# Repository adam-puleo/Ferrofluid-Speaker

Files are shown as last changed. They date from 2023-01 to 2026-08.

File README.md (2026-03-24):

# Ferrofluid-Speaker
A ferrofluid Bluetooth speaker.

Use --recurse-submodules to clone this repo: ```git clone --recurse-submodules https://github.com/adam-puleo/Ferrofluid-Speaker.git```

## Version 2
https://github.com/user-attachments/assets/a1edecc6-fbbd-465e-8119-4edb1a70faee

## Version 2 Front
v2_front

## Version 2 Back
v2_back

## Prototype


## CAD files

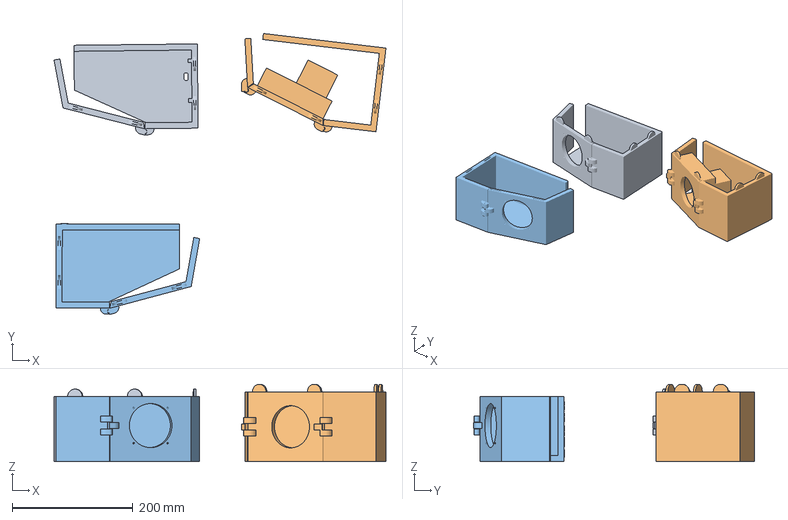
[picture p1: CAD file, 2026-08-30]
Case/Tilted Case Frame.3mf
550.5 x 466.0 x 128.5 mm
Tilted Case Frame Left
Tilted Case Frame Middle
Tilted Case Frame Right

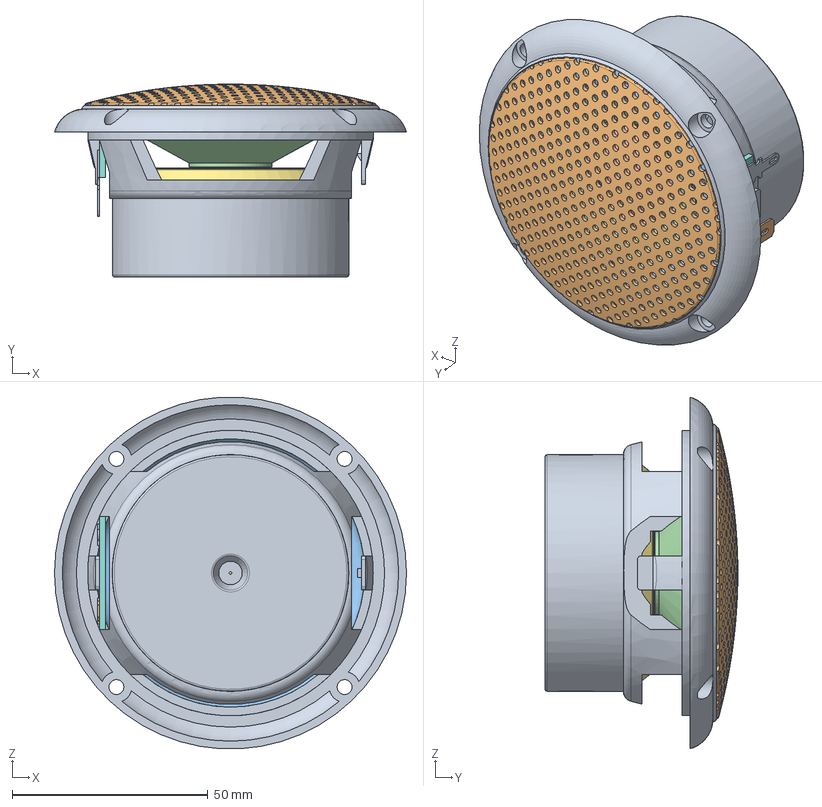
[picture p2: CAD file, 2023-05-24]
Case/VISATON FR 8 WP 130814-igs-stp/FR 8 WP 130814.stp
90.0 x 49.3 x 89.8 mm
FR 8 WP - Korb 130814
FR 8 WP - Gitter 130814
FR 8 WP - T-Yoke 130814
FR 8 WP - Magnet 130814
FR 8 WP - Polplatte 130814
FR 8 WP - Schraube für Magnetbefestigung 130814
FR 8 WP - Terminalplatte 130814
_Terminal 2.8-0.5
_Terminal 5.1-0.5
FR 8 WP - Sicke 130814
FR 8 WP - Membran 130814
FR 8 WP - Staubschutzkalotte 130814
FR 8 WP - Spule 130814
FR 8 WP - Zentrierspinne 130814

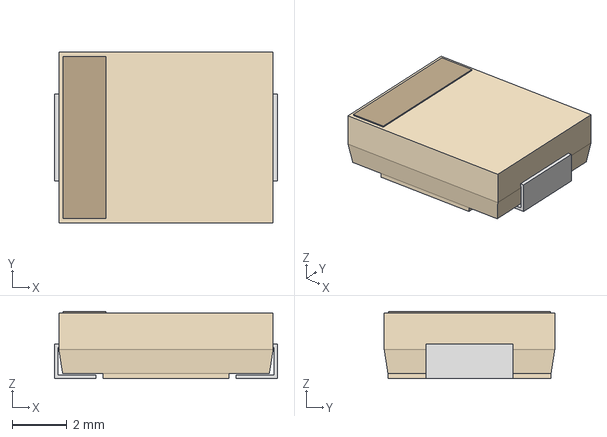
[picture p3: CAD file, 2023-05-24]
Circuits/Main Circuit/B520C-13-F/SMC_DIO.step
8.13 x 6.22 x 2.45 mm

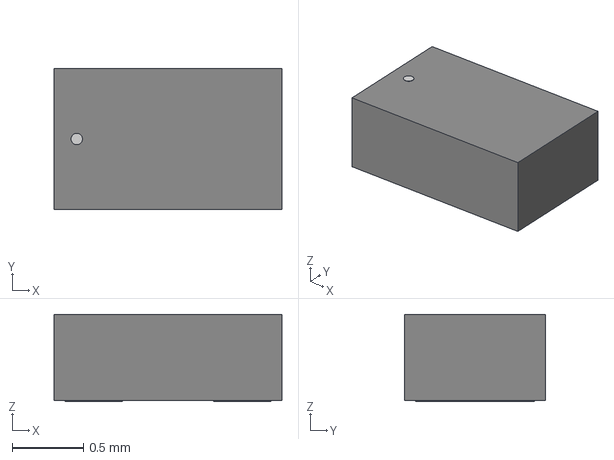
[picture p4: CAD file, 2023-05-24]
Circuits/Main Circuit/ESDA25P35-1U1M/QFN1610_STM.step
1.60 x 0.99 x 0.612 mm

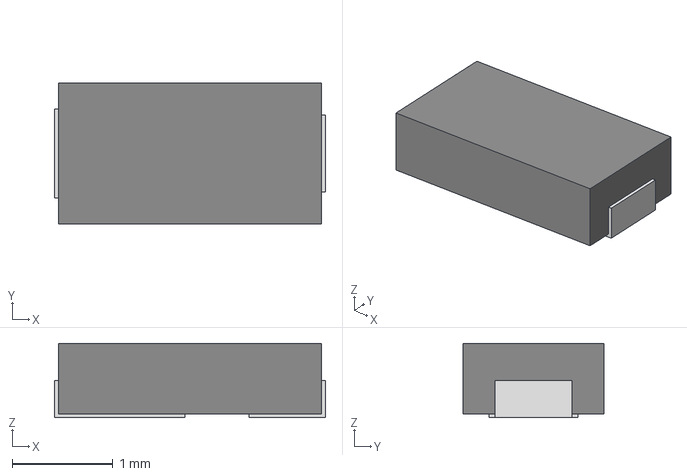
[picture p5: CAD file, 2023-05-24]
Circuits/Main Circuit/MSS1P3L-M3:89A/DIODE_MSP3V3.step
2.69 x 1.40 x 0.737 mm

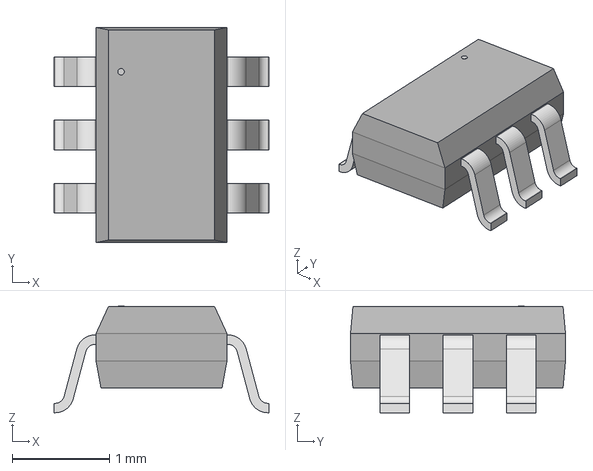
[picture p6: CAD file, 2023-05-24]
Circuits/Main Circuit/NVJS4405NT1G/SOT-363-6_2P2X1P35_ONS.step
2.21 x 2.21 x 1.09 mm

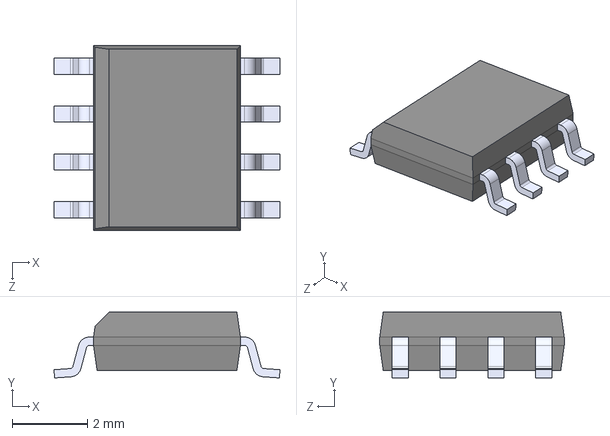
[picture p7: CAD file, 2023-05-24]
Circuits/Main Circuit/SI4485DY-T1-GE3.STEP
6.00 x 1.75 x 4.90 mm

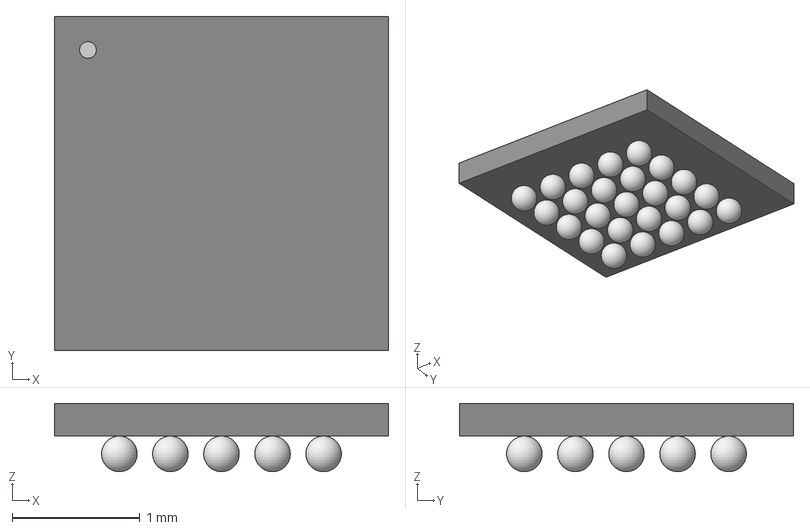
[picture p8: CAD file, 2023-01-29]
Circuits/Main Circuit/ul_STUSB4500BJR/Fusion360/BGA_00BJR_STM.step
2.62 x 2.62 x 0.536 mm

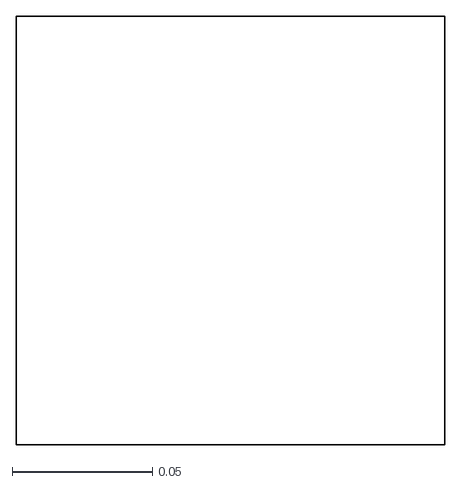
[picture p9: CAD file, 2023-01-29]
Circuits/Main Circuit/ul_STUSB4500BJR/Library_View.dxf
0.153 x 0.153

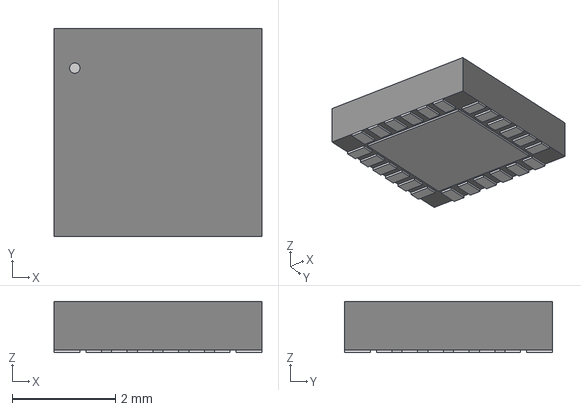
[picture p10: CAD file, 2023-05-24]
Circuits/Main Circuit/ul_STUSB4500QTR/Fusion360/QFN24EP_4X4_STM.step
4.04 x 4.04 x 0.993 mm

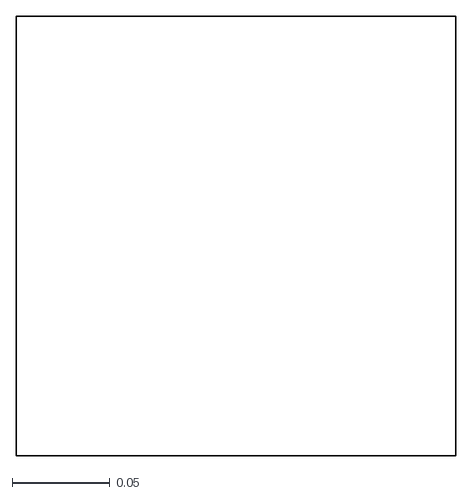
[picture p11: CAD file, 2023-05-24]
Circuits/Main Circuit/ul_STUSB4500QTR/Library_View.dxf
0.225 x 0.225

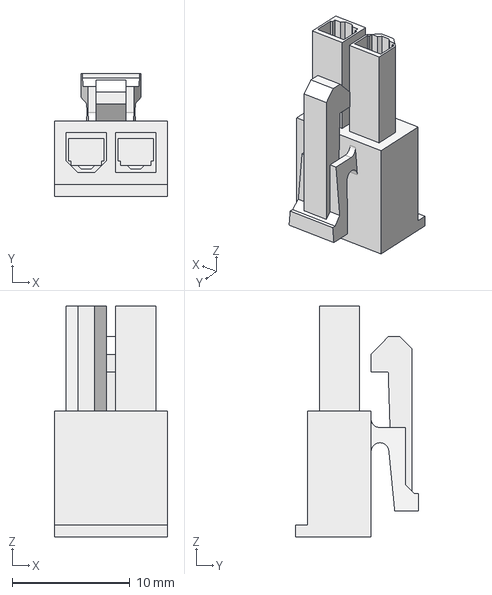
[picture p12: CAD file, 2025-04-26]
Case/Download_STP_649002013322_rev1.stp
9.60 x 10.4 x 19.6 mm

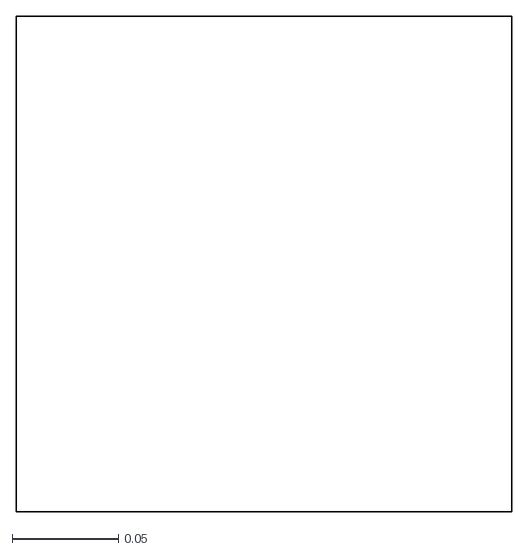
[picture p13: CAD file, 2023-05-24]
Circuits/Main Circuit/ul_STUSB4500QTR/QFN24EP_4X4_STM.dxf
0.233 x 0.233

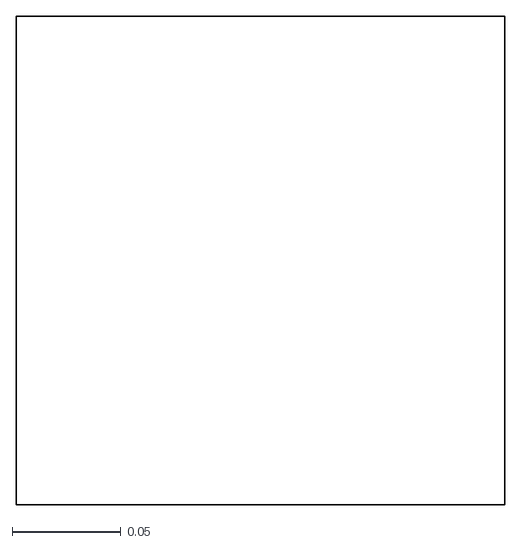
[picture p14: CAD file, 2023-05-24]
Circuits/Main Circuit/ul_STUSB4500QTR/QFN24EP_4X4_STM-L.dxf
0.225 x 0.225

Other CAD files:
Circuits/Main Circuit/ul_STUSB4500QTR/QFN24EP_4X4_STM-M.dxf
Electromagnets/EM175GenericModel v2.f3d
Ferrofluid Bottles/Ferrofluid Bottle v4.f3d

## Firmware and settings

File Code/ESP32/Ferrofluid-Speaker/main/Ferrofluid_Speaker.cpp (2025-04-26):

/*
    Inspiration for this came from Seung Hoon Jung's ferrofluid speaker.
    https://makezine.com/article/craft/fine-art/we-cant-stop-watching-this-diy-ferrofluid-bluetooth-speaker/

    Tested with ESP-ADF v2.7 (db46237027988356673c150348c3294862105d51), ESP-IDF v5.4, ESP32-A2DP v1.8.7, arduino-audio-tools (13ae8ea75c7113f048f28e11d91357942e93716f)

    menuconfig
    Partition Table
        Partition Table
            Single factory app (large), no OTA
    Compiler options
        Optimization Level -> Optimize for performance (-O2)
    Component config
        Bluetooth
            Controller Options
                Bluetooth controller mode -> BR/EDR Only
            Bluedroid Options
                Classic Bluetooth -> A2DP & SPP
        Log
            Log Level
                Default log verbosity -> No output

    Test Music:
        Artist: Tom Misch
        Album: Geography
        Song: Movie

        Artist: Metallica
        Album: 72 Seasons
        Song: Lux Æterna

        Artist: Ozzy Osbourne
        Album: Memoirs of a Madman
        Song: Crazy Train

        Artist: Queens of the Stone Age
        Album: Songs for the Deaf
        Song: No One Knows

        Artist: Iron Maiden
        Album: Senjutsu
        Song: Senjutsu
*/

#include <time.h>
#include <stdio.h>
#include <stdlib.h>
#include <string.h>
#include <assert.h>
#include "freertos/FreeRTOS.h"
#include "freertos/task.h"
#include "esp_system.h"
#include "esp_dsp.h"
#include "driver/i2c_master.h"
#include "driver/gpio.h"
#include "esp_timer.h"

#include "AudioTools.h"
#include "BluetoothA2DPSink.h"
#include "TAS5805M.hpp"
#include "STUSB4500.hpp"

// Vars for logging
const char *TAG = "Ferrofluid";
const int64_t OUTPUT_INTERVAL = 2000000; // Two seconds
int64_t last_output = 0;

// Setup aliases for GPIO pins that drive the electromagnet.
const gpio_num_t MAGNET = GPIO_NUM_5;

// Fast fourier transform variables.
const size_t NUM_FFT_SAMPLES = 4096 / 2 / 2; // See read_data_stream
static_assert(NUM_FFT_SAMPLES == 1024, "FFT lib requires 1024 samples.");
// Window coefficients
__attribute__((aligned(16))) float fft_window[NUM_FFT_SAMPLES];
// working complex array
__attribute__((aligned(16))) float y_cf[NUM_FFT_SAMPLES * 2];
// Pointers to result arrays
float *fft_output_left = &y_cf[0];
float *fft_output_right = &y_cf[NUM_FFT_SAMPLES];

// Setup config constants for ESP's I2C communications.
const uint32_t I2C_FREQUENCY = 400000;
const i2c_port_t I2C_PORT = I2C_NUM_0;
const uint8_t AMP_ADDR = 0x2C;      // Amp's I2C address (8-bit write address: 0x58)
const uint8_t USB_CTRL_ADDR = 0x2B; // USB controller's I2C address (8-bit write address: 0x56)
const int I2C_XFER_TIMEOUT = -1;
const gpio_num_t I2C_GPIO_SCL = GPIO_NUM_19;
const gpio_num_t I2C_GPIO_SDA = GPIO_NUM_18;
i2c_master_bus_config_t i2c_mst_config = {
    .i2c_port = I2C_PORT,
    .sda_io_num = I2C_GPIO_SDA,
    .scl_io_num = I2C_GPIO_SCL,
    .clk_source = I2C_CLK_SRC_DEFAULT,
    .glitch_ignore_cnt = 7,
    .intr_priority = 0,
    .trans_queue_depth = 0,
    .flags{.enable_internal_pullup = true, // ESP32's pull-ups are only good for 100kHz; set to true to remove warning.
           .allow_pd = false,
        },
};
i2c_master_bus_handle_t bus_handle;

// Setup aliases for GPIO pins that communicate with the amp.
const gpio_num_t PDN = GPIO_NUM_23;
const gpio_num_t FAULT = GPIO_NUM_21;
const gpio_num_t I2S_LRCLK = GPIO_NUM_25;
const gpio_num_t I2S_SCLK = GPIO_NUM_26;
const gpio_num_t I2S_DIN = GPIO_NUM_22;

// I2C interface variables for TAS5805M.
i2c_wrapper *i2c_tas5805m;
TAS5805M *amp;

// Constants for USB / power requirements.
const unsigned int M_VOLTS = 12000; // Millivolts
const unsigned int M_AMPS = 1000;   // Milliamps

// I2C interface variables to STUSB4500.
i2c_wrapper *i2c_usb_ctrler;
STUSB4500 *usb_ctrler;

// Setup the Bluetooth A2DP sink and I2S.
I2SStream i2s;
BluetoothA2DPSink a2dp_sink(i2s);

#define CHECK_ERROR(error_code, ...)  \
    if (error_code != ESP_OK)         \
    {                                 \
        ESP_LOGE(TAG, ##__VA_ARGS__); \
        return error_code;            \
    }

void read_data_stream(const uint8_t *data, uint32_t length)
{
    // *data contains left and right channel data. First two bytes is left (int16_t).
    // Next two bytes is the right channel data. length contains the total number of
    // bytes.
    ESP_LOGD(TAG, "Length: %d", length);
    size_t sample_count = length / 2 / 2;
    if (sample_count != NUM_FFT_SAMPLES)
    {
        ESP_LOGE(TAG, "Sample Count: %d", sample_count);
        assert(sample_count == NUM_FFT_SAMPLES);
    }

    // Create a new pointer cast as 16 bits.
    int16_t *samples = (int16_t *)data;

    // FFT analysis lifted from https://github.com/espressif/esp-dsp/blob/master/examples/fft/main/dsps_fft_main.c
    // Convert two input vectors to one complex vector and apply window function.
    for (int i = 0; i < NUM_FFT_SAMPLES; i++) {
        y_cf[i * 2 + 0] = float(samples[i]) * fft_window[i];
        y_cf[i * 2 + 1] = float(samples[i + 1]) * fft_window[i];
    }

    // Execute the FFT
    dsps_fft2r_fc32(y_cf, NUM_FFT_SAMPLES);
    // Bit reverse
    dsps_bit_rev_fc32(y_cf, NUM_FFT_SAMPLES);
    // Convert one complex vector to two complex vectors
    dsps_cplx2reC_fc32(y_cf, NUM_FFT_SAMPLES);
    // FFT returns complex numbers, where the first half of y_cf is the left channel and the second
    // half of y_cf is the right channel.

    bool high_freq = false;
    const int current_volume = a2dp_sink.get_volume();
    // If the normalized value is above 63% of the max volume, turn on the magnet.
    const float fft_threshold = (float(current_volume) / INT8_MAX) * (exp2(11) - 1) * 0.63;
    for (int i = 0; i < NUM_FFT_SAMPLES / 2; i++) {
        // Compute the normalized output so it can be compared with the maximum (current volume).
        float normalized_left = 2.0 * (sqrtf(fft_output_left[i * 2 + 0] * fft_output_left[i * 2 + 0] + fft_output_left[i * 2 + 1] * fft_output_left[i * 2 + 1]) / NUM_FFT_SAMPLES);
        float normalized_right = 2.0 * (sqrtf(fft_output_right[i * 2 + 0] * fft_output_right[i * 2 + 0] + fft_output_right[i * 2 + 1] * fft_output_right[i * 2 + 1]) / NUM_FFT_SAMPLES);

        if (normalized_left > fft_threshold || normalized_right > fft_threshold)
        {
            ESP_LOGI(TAG, "Current volume: %d, Threshold: %f", current_volume, fft_threshold);
            ESP_LOGI(TAG, "%d-th freq (%dHZ) - Left: %f, Right: %f", i, (i * a2dp_sink.sample_rate()) / NUM_FFT_SAMPLES, fft_output_left[i], fft_output_right[i]);
            // ESP_LOGI(TAG, "Input Left: %d, Input Right: %d", samples[i * 2], samples[i * 2 + 1]);
            gpio_set_level(MAGNET, 1);
            high_freq = true;
            break;
        }

        if (!high_freq)
        {
            gpio_set_level(MAGNET, 0);
        }
    }
}

void i2s_state_change_pre(esp_a2d_audio_state_t state, void *obj)
{
    switch (state)
    {
    case ESP_A2D_AUDIO_STATE_STARTED:
        amp->start_pre_i2s();
        break;

    case ESP_A2D_AUDIO_STATE_SUSPEND:
        amp->stop();
        gpio_set_level(MAGNET, 0);
        break;

    default:
        break;
    }
}

void i2s_state_change_post(esp_a2d_audio_state_t state, void *obj)
{
    switch (state)
    {
    case ESP_A2D_AUDIO_STATE_STARTED:
        amp->start_post_i2s();
        break;

    case ESP_A2D_AUDIO_STATE_SUSPEND:
        amp->stop();

        gpio_set_level(MAGNET, 0);
        break;

    default:
        break;
    }
}

bool setup()
{
    esp_err_t result;

    // Setup I2C bus.
    ESP_ERROR_CHECK(i2c_new_master_bus(&i2c_mst_config, &bus_handle));

    // Setup I2C for TAS5805M.
    i2c_tas5805m = new i2c_wrapper(&bus_handle, I2C_FREQUENCY, AMP_ADDR, I2C_XFER_TIMEOUT);
    amp = new TAS5805M(i2c_tas5805m, PDN, FAULT);

    // Setup I2C for STUSB4500.
    i2c_usb_ctrler = new i2c_wrapper(&bus_handle, I2C_FREQUENCY, USB_CTRL_ADDR, I2C_XFER_TIMEOUT);
    usb_ctrler = new STUSB4500(i2c_usb_ctrler);

    // Confirm power
    unsigned int m_volt;
    unsigned int m_amp;
    bool mismatch;

    result = usb_ctrler->read_power(&m_volt, &m_amp, &mismatch);
    CHECK_ERROR(result, "First power read failed: %s", esp_err_to_name(result));
    if (mismatch || m_volt != M_VOLTS || m_amp < M_AMPS)
    {
        ESP_LOGD(TAG, "setting up power requirements");
        result = usb_ctrler->set_power(M_VOLTS, M_AMPS);
        CHECK_ERROR(result, "Set power failed: %s", esp_err_to_name(result));

        result = usb_ctrler->read_power(&m_volt, &m_amp, &mismatch);
        CHECK_ERROR(result, "Second power read failed: %s", esp_err_to_name(result));
        if (mismatch || m_volt < M_VOLTS || m_amp < M_AMPS)
        {
            // Still do not have the required power. Stop powering up.
            ESP_LOGE(TAG, "Power mismatch");
            ESP_LOGE(TAG, "mismatch: %d", mismatch);
            ESP_LOGE(TAG, "m_volt: %d", m_volt);
            ESP_LOGE(TAG, "m_amp: %d", m_amp);
            return false;
        }
    }

    // Configure pin for magnet.
    gpio_config_t io_conf = {};
    // Set the bit mask for the output pins.
    io_conf.pin_bit_mask = ((1ULL << MAGNET));
    // Set all pins as output mode
    io_conf.mode = GPIO_MODE_OUTPUT;
    // Disable pull-down mode
    io_conf.pull_down_en = GPIO_PULLDOWN_DISABLE;
    // Disable pull-up mode
    io_conf.pull_up_en = GPIO_PULLUP_DISABLE;
    // Configure GPIO pins with the given settings
    result = gpio_config(&io_conf);
    CHECK_ERROR(result, "Could not configure output pins: %d", result);
    gpio_set_level(MAGNET, 0);
    /*gpio_set_level(LEFT_LED, 0);
    gpio_set_level(CENTER_LED, 0);
    gpio_set_level(RIGHT_LED, 0);*/

    // Initialize the FFT
    result = dsps_fft2r_init_fc32(NULL, CONFIG_DSP_MAX_FFT_SIZE);
    CHECK_ERROR(result, "Could not initialize FFT. Error = %i", result);
    // Generate Hann window
    dsps_wind_hann_f32(fft_window, NUM_FFT_SAMPLES);

    /* initialize NVS — it is used to store PHY calibration data */
    esp_err_t err = nvs_flash_init();
    if (err == ESP_ERR_NVS_NO_FREE_PAGES || err == ESP_ERR_NVS_NEW_VERSION_FOUND) {
        ESP_ERROR_CHECK(nvs_flash_erase());
        err = nvs_flash_init();
    }
    ESP_ERROR_CHECK(err);

    // Configure Bluetooth (and I2S) library.
    auto cfg = i2s.defaultConfig();
    cfg.pin_bck = I2S_SCLK;
    cfg.pin_ws = I2S_LRCLK;
    cfg.pin_data = I2S_DIN;
    i2s.begin(cfg);

    a2dp_sink.set_stream_reader(read_data_stream);
    a2dp_sink.set_on_audio_state_changed(i2s_state_change_pre, NULL);
    a2dp_sink.set_on_audio_state_changed_post(i2s_state_change_post, NULL);
    // a2dp_sink.set_bits_per_sample(24);  // Bad things seem to happen when set to 24. The ESP can't keep up with the BT data.
    //  Enable Bluetooth which will also enable I2S (a2dp_sink.start)
    a2dp_sink.start("Ferrofluid");

    return true;
}

extern "C" void app_main(void)
{
    if (setup())
    {
        a2dp_sink.set_volume(UINT8_MAX / 2 / 2);
        while (true)
        {
            if (amp->error())
            {
                ESP_LOGE(TAG, "Amp's FAULT_PIN is active.");
                a2dp_sink.stop();
                break;
            }
            vTaskDelay(500 / portTICK_PERIOD_MS);  // Check the amp for errors every half second.
        }
    }
}

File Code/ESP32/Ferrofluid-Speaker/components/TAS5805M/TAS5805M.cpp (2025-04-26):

#include "driver/gpio.h"
#include "freertos/FreeRTOS.h"
#include "TAS5805M.hpp"

#define LOG_LOCAL_LEVEL ESP_LOG_WARN
const char* TAS5805M_TAG = "TAS5805M";
#include "esp_log.h"

// Constructor
TAS5805M::TAS5805M(i2c_wrapper *i2c_interface,
                   const gpio_num_t pdn_pin,
                   const gpio_num_t fault_pin) {
    this->i2c_interface = i2c_interface;
    this->PDN = pdn_pin;
    this->FAULT = fault_pin;

    /* 2.0 Stereo BTL system, Figure 8-2, section 8.2.1.1 */
    /* See 7.5.2.5 DSP Memory Book, Page about how to address memory */
    /* See 7.5.3.1 Startup Procedures */

    gpio_config_t io_conf = {};
    // Set the bit mask for the PDN output pin.
    io_conf.pin_bit_mask = (1ULL << PDN);
    // Set pin as output mode
    io_conf.mode = GPIO_MODE_OUTPUT;
    // Disable pull-down mode
    io_conf.pull_down_en = GPIO_PULLDOWN_DISABLE;
    // Disable pull-up mode
    io_conf.pull_up_en = GPIO_PULLUP_DISABLE;
    // Configure GPIO pin with the given settings
    ESP_ERROR_CHECK(gpio_config(&io_conf));

    // Reset the variable
    io_conf = {};
    // Set the bit mask for the input pins.
    io_conf.pin_bit_mask = (1ULL << FAULT);
    // Set as input mode
    io_conf.mode = GPIO_MODE_INPUT;
    // Configure GPIO pins with the given settings
    ESP_ERROR_CHECK(gpio_config(&io_conf));
}

esp_err_t TAS5805M::start_pre_i2s() {
    esp_err_t result;

    // We do not know what state the chip is in, make sure it's powered down before starting it.
    result = stop();
    if (result != ESP_OK) {
        return result;
    }

    // Enable the amp (TAS5805M).
    result = gpio_set_level(PDN, 1);
    if (result == ESP_OK) {
        state = DEEP_SLEEP;
        // Per specification, wait at least 5ms before enabling the I2S clocks.
        vTaskDelay(pdMS_TO_TICKS(10));
    } else {
        ESP_LOGE(TAS5805M_TAG, "ERROR: Could not bring PDN high: %d", result);
    }
    return result;
}

esp_err_t TAS5805M::start_post_i2s() {
    esp_err_t result;

    // Wait 100ms for I2S to settle, just for giggles.
    vTaskDelay(pdMS_TO_TICKS(100));

    /* Send commands to initialize the TAS5805M. */

    /* Section 7.5.2.5 of the TAS5805M Data Sheet explains pages and books. */
    /* Go to page zero. */
    const uint8_t PAGE_ZERO[] = {PAGE_REG, 0x00};
    result = this->i2c_interface->send_i2c_commands(I2C_MASTER_WRITE,
                               PAGE_ZERO, sizeof(PAGE_ZERO),
                               NULL, 0);
    if (result != ESP_OK) {
        ESP_LOGE(TAS5805M_TAG, "ERROR: Could not move to page zero: %s", esp_err_to_name(result));
        return result;
    }

    /* Go to book zero. */
    const uint8_t BOOK_ZERO[] = {BOOK_REG, 0x00};
    result = this->i2c_interface->send_i2c_commands(I2C_MASTER_WRITE,
                               BOOK_ZERO, sizeof(BOOK_ZERO),
                               NULL, 0);
    if (result != ESP_OK) {
        ESP_LOGE(TAS5805M_TAG, "ERROR: Could not move to book zero: %s", esp_err_to_name(result));
        return result;
    }

    /* Go to page zero. */
    result = this->i2c_interface->send_i2c_commands(I2C_MASTER_WRITE,
                               PAGE_ZERO, sizeof(PAGE_ZERO),
                               NULL, 0);
    if (result != ESP_OK) {
        ESP_LOGE(TAS5805M_TAG, "ERROR: Could not move to page zero of book zero: %s", esp_err_to_name(result));
        return result;
    }

    /* Move amp to HiZ state */
    const uint8_t HiZ_CMDS[] = {DEVICE_CTRL_2, 0b10};
    result = this->i2c_interface->send_i2c_commands(I2C_MASTER_WRITE,
                               HiZ_CMDS, sizeof(HiZ_CMDS),
                               NULL, 0);
    if (result != ESP_OK) {
        ESP_LOGE(TAS5805M_TAG, "ERROR: Could not setup amp (HiZ): %s", esp_err_to_name(result));
        return result;
    }

    state = HiZ;

    /* Per specification (7.5.3.1) wait at least 5ms for device to settle. */
    vTaskDelay(pdMS_TO_TICKS(10));

    /* Set the volume to the middle of the road so we don't blast out someone's ears when we turn on. */
    const uint8_t VOL_CMDS[] = {DIG_VOL_CTL, 0b00110000};
    result = this->i2c_interface->send_i2c_commands(I2C_MASTER_WRITE,
                               VOL_CMDS, sizeof(VOL_CMDS),
                               NULL, 0);

    /* Set the analog gain so that we do not go over 12v. */
    /* Set 0x54, AGAIN[4:0] to 12v, see section 7.3.8.1 & section 7.6.1.21
    12v system so gain (AGAIN) should be set to 0x15, to produce a peak output voltage of 12v. 
    Assuming linear: y=mx+b
    x=0; b=29.5
    x=31; y=4.95; m=-0.79
    x=(y-b)/m=(12-29.5)/-0.79=22
    Round up a little and AGAIN_REG should be 23. */
    const uint8_t AGAIN_CMDS[] = {AGAIN_REG, 0x17};
    result = this->i2c_interface->send_i2c_commands(I2C_MASTER_WRITE, 
                               AGAIN_CMDS, sizeof(AGAIN_CMDS),
                               NULL, 0);
    if (result != ESP_OK) {
        ESP_LOGE(TAS5805M_TAG, "ERROR: Could not setup amp (AGAIN): %s", esp_err_to_name(result));
        return result;
    }

    /* Setup the ADR/FAULT pin to signal when there is a fault. */
    /* Set ADR/FAULT pin to output fault, set reg 0x61 = 0x0b then 0x60 = 0x01, section 5 */
    const uint8_t FAULT1_CMDS[] = {ADR_PIN_CONFIG, 0b01011};
    result = this->i2c_interface->send_i2c_commands(I2C_MASTER_WRITE, 
                               FAULT1_CMDS, sizeof(FAULT1_CMDS),
                               NULL, 0);
    if (result != ESP_OK) {
        ESP_LOGE(TAS5805M_TAG, "ERROR: Could not setup amp (ADR/FAULT 1): %s", esp_err_to_name(result));
        return result;
    }

    /* Finish setting up the ADR/FAULT pin. */
    /* Set ADR/FAULT pin to output fault, set reg 0x61 = 0x0b then 0x60 = 0x01, section 5 */
    const uint8_t FAULT2_CMDS[] = {ADR_PIN_CTRL, 0b1};
    result = this->i2c_interface->send_i2c_commands(I2C_MASTER_WRITE,
                               FAULT2_CMDS, sizeof(FAULT2_CMDS),
                               NULL, 0);
    if (result != ESP_OK) {
        ESP_LOGE(TAS5805M_TAG, "ERROR: Could not setup amp (ADR/FAULT 2): %s", esp_err_to_name(result));
        return result;
    }

    /* Are these next two required? */
    /* 7.6.1.5 SIG_CH_CTRL Register (Offset = 28h) needs to be set to match I2S audio, defaults to auto detect. */

    /* 7.6.1.9 SAP_CTRL1 Register, does does word length need to be changed from default of 24 bits? */
    /* ESP defaults to 16. When the ESP is set to 24 it freaks out. */
    const uint8_t SAP_CTRL1_CMDS[] = {SAP_CTRL1, 0b00};
    result = this->i2c_interface->send_i2c_commands(I2C_MASTER_WRITE,
                               SAP_CTRL1_CMDS, sizeof(SAP_CTRL1_CMDS),
                               NULL, 0);
    if (result != ESP_OK) {
        ESP_LOGE(TAS5805M_TAG, "ERROR: Could not setup amp (I2S bits): %s", esp_err_to_name(result));
        return result;
    }
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

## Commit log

2022-08-08 added local files
    [EM175GenericModel v2.f3d, Electromagnet Holder 100lb v8.f3z, Ferrofluid Bottle v4.f3d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]
2022-08-20 organized files, updated circuit and holder to have one magnet and three leds
    [EM150-12-222 v2.f3d, EM175GenericModel v2.f3d, Electromagnet Holder 100lb v8.f3z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]
2022-08-20 removed 88lb magnet, no longer used
    [EM150-12-222 v2.f3d]
2022-08-30 switch to one magnet
2022-08-30 switch to one magnet and three LEDs that are always on
    [Ferrofluid Speaker v17.f3z]
2022-08-30 nothing significant
    [Electromagnet Holder One 100lb v3.3mf, Electromagnet Holder One 100lb v3.f3z, Electromagnet Holder One 100lb v5.3mf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]
2022-10-20 added a continuous fft with a stride and USB-C circuit
2023-01-29 migrated to i2c-wrapper lib
2023-01-29 added support for i2c-wrapper and STUSB4500
2023-01-29 newer circuit available
2023-01-29 STUSB4500BJR chip
    [BGA_00BJR_STM.dxf, BGA_00BJR_STM.step, Library_View.dxf]
2023-01-29 switched to my fork
2023-05-24 final circuit that was manufactured
    [DIODE_MSP3V3.step, Library_View.dxf, QFN1610_STM.step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]
2023-05-24 creating a case
    [Case Center v11.3mf, Case Left v11.3mf, Case Right v11.3mf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]
2023-07-09 removed pot
    [Case Center v11.3mf, Case Left v11.3mf, Case Right v11.3mf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]
2024-09-16 updated to latest esp-adf, esp-idf 5.3.1, esp32-a2dp 1.8.3
2024-09-16 removed holders since theres a case now
    [Electromagnet Holder One 100lb v5.3mf, Electromagnet Holder One 100lb v5.f3z]
2025-04-26 updated ESP32 and phils libs and made a new case
    [Download_STP_649002013322_rev1.stp, Tilted Case Fame v21.3mf]
2025-05-06 final case and audio tools mod
    [Tilted Case Fame v21.3mf]
2025-05-06 switching back to master repo
2025-05-06 switched to main repo
2026-03-24 Add version 2 images and prototype to README
2026-08-30 Clean up case files.
    [Case no POT v3.3mf, Case no POT v3.f3z, Tilted Case Fame v21.3mf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]
2026-11-10 code fixes and a new case
2026-11-10 Update README to include Version 3 case
    Added Version 3 section with link to assets.
